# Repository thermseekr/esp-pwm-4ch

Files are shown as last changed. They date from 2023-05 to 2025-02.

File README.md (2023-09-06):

# ESP-PWM-4CH

ESP8266/ESP32 based board with 4x PWM output channels.

This board is designed to be driven by an Olimex ESP32-POE, ESP32-POE-ISO or Wemos D1 Mini modules.

The design considers that the board will be mounted on a PCB DIN rail holder offered by the Brazilian manufacturer Metaltex. Check [here](https://www.metaltex.com.br/produtos/componentes/suportes/sp7-suporte-para-montagem-de-placa-de-circuito-impresso-em-trilho-din) for details.

Heatsinks are included in the design as I wasn't sure about how much power the MOSFETs would dissipate. The first tests were performed using zero ohm resistors between the drivers and the transistors. A 5A load was applied and the transistor showed no noticeable temperature elevation. In version 2 I replaced the zero ohm resistors for 22 ohm to protect the drivers. Given the very low switching frequency and small loads I suppose the heatsinks are still not needed.

Expect some flicker when driving LEDs with the ESP8266. It gets much more stable when using the hardware PWMs of the ESP32.

There is a preferred version of this board with 8x PWM channels and individual pins for powering groups of two outputs, what enables driving the full 5A per channel. Click [here](https://github.com/thermseekr/esp-pwm-8ch) to check it.

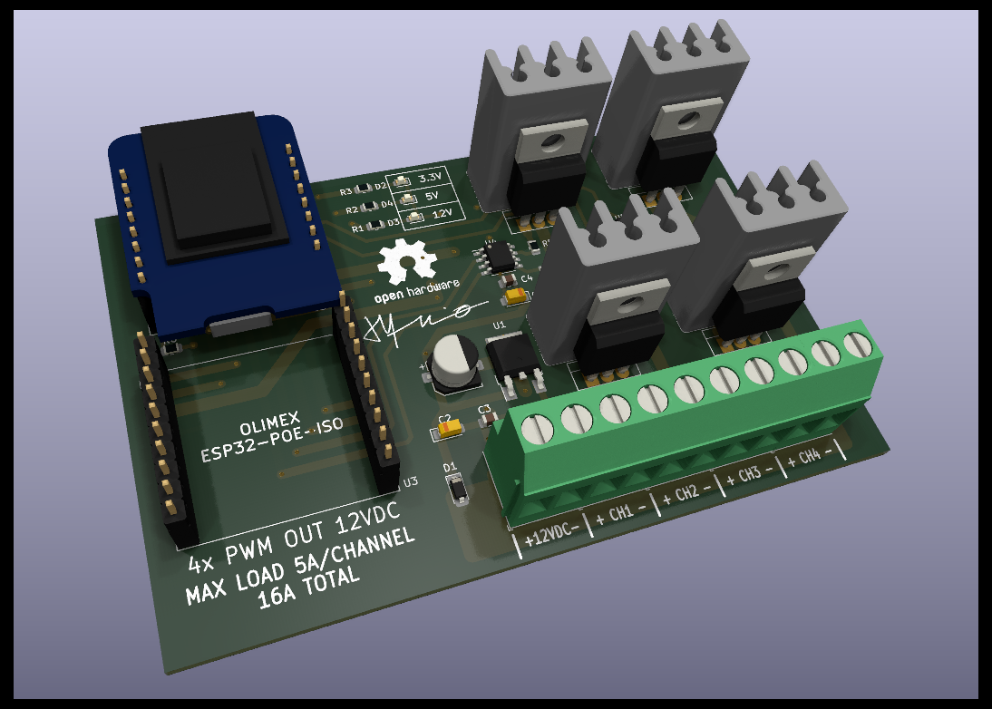
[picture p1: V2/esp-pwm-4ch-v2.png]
ESP-PWM-4CH


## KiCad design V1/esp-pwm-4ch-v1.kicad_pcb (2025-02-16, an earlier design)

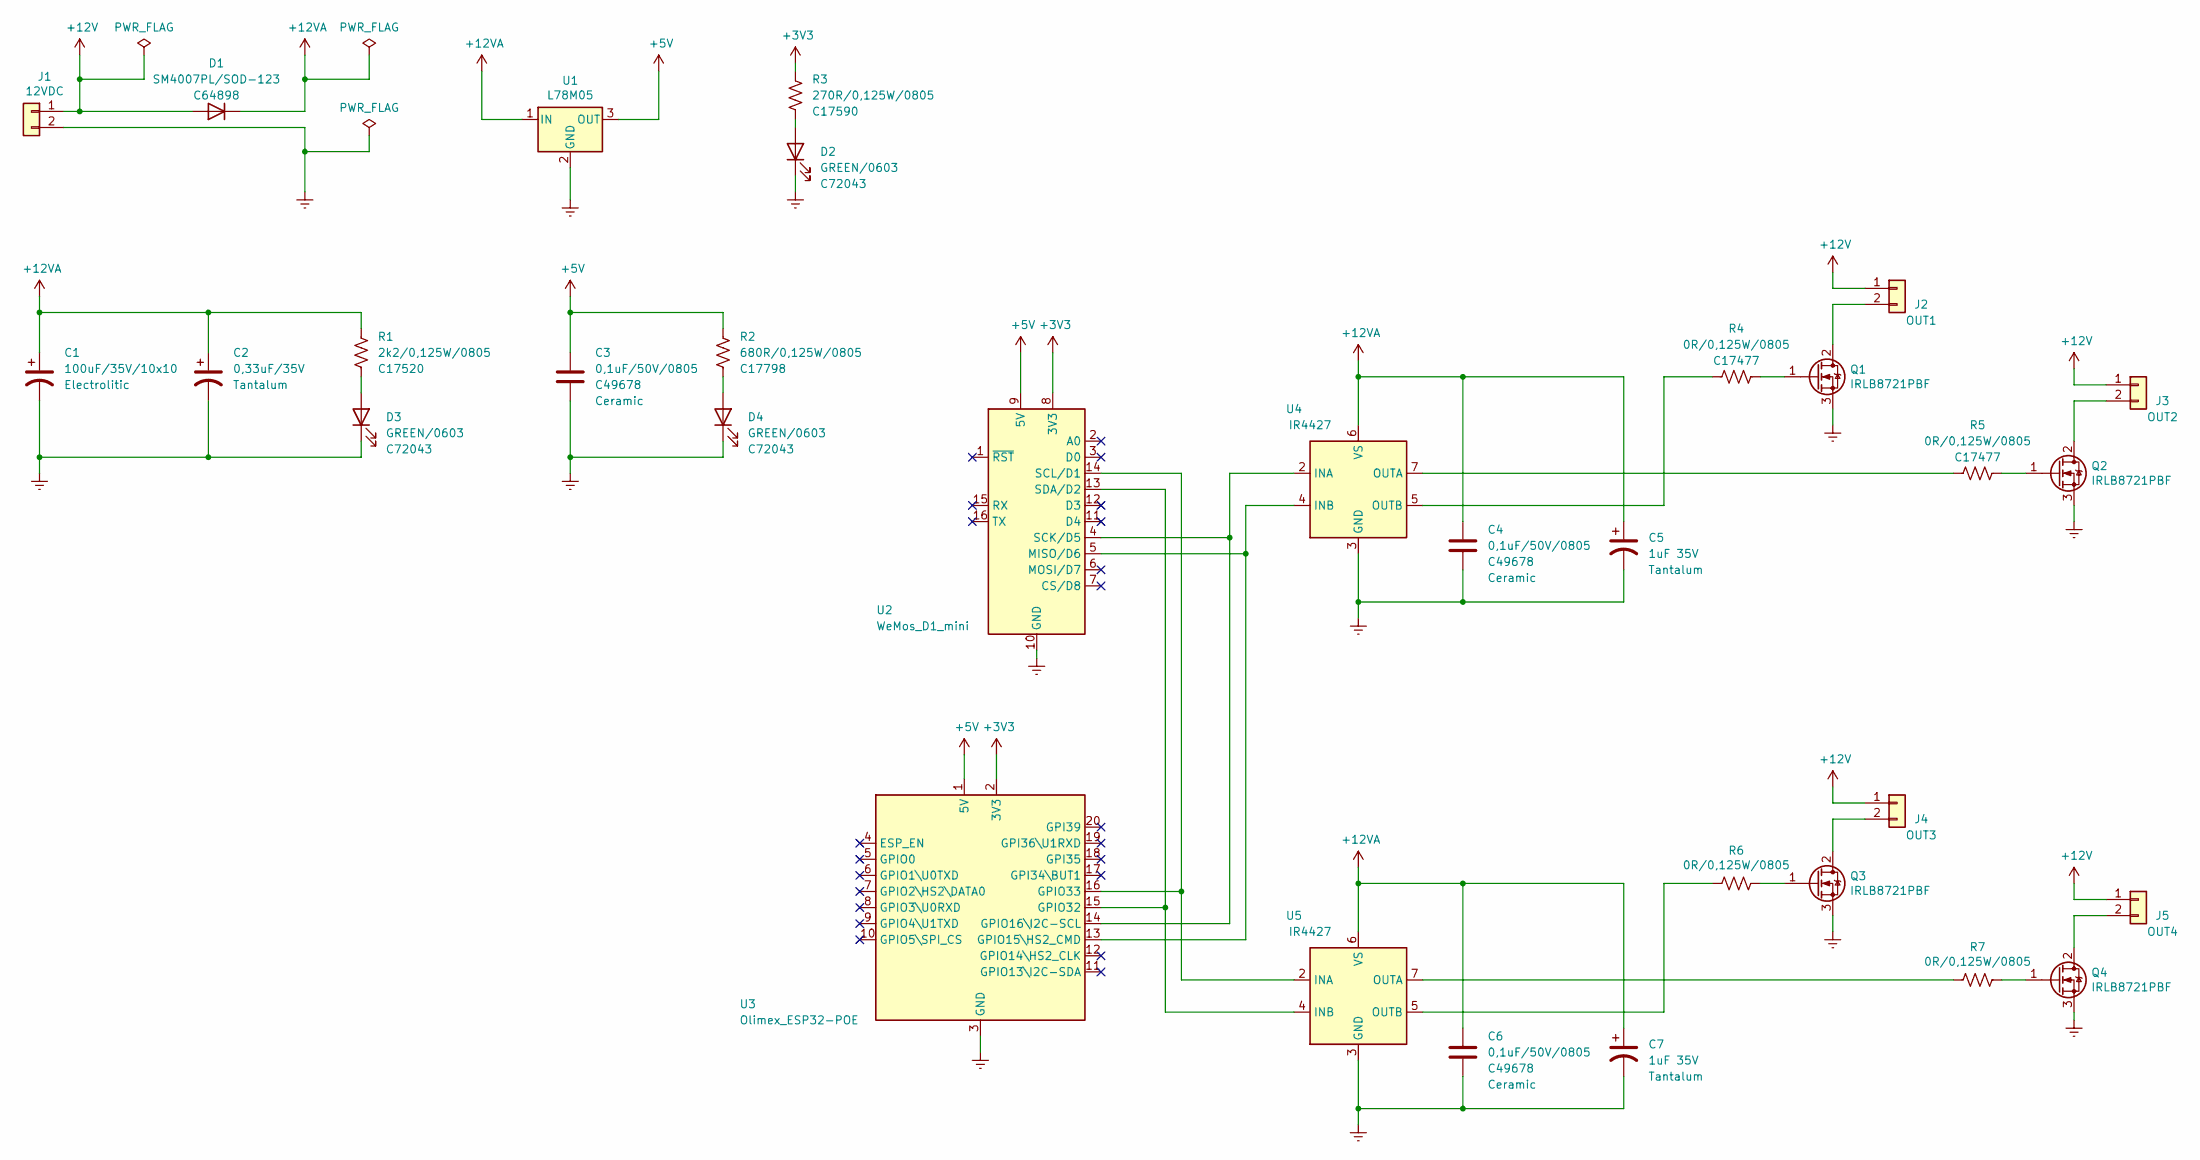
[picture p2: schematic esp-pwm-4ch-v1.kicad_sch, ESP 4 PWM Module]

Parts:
C1: 100uF/35V/10x10; CP_Elec_10x10; Mfr PN MAL214097001E3; JLCPCB BOM 0
C2: 0,33uF/35V; CP_EIA-3216-18_Kemet-A_Pad1.58x1.35mm_HandSolder; Mfr PN TAJA334K035RNJ; JLCPCB BOM 0
C3, C4, C6: 0,1uF/50V/0805; C_0805_2012Metric; Mfr PN CC0805KRX7R9BB104; JLCPCB BOM 1
C5, C7: 1uF 35V; CP_EIA-3216-18_Kemet-A_Pad1.58x1.35mm_HandSolder; Mfr PN TAJA105K035TNJ; JLCPCB BOM 0
D1: SM4007PL/SOD-123; D_SOD-123; Mfr PN SM4007PL; JLCPCB BOM 1
D2, D3, D4: GREEN/0603; LED_0603_1608Metric; Mfr PN 19-217/GHC-YR1S2/3T; JLCPCB BOM 1
J1: 12VDC; TerminalBlock_Phoenix_MKDS-3-2-5.08_1x02_P5.08mm_Horizontal; Mfr PN BR902V; JLCPCB BOM 0
J2: OUT1; TerminalBlock_Phoenix_MKDS-3-2-5.08_1x02_P5.08mm_Horizontal; Mfr PN BR902V; JLCPCB BOM 0
J3: OUT2; TerminalBlock_Phoenix_MKDS-3-2-5.08_1x02_P5.08mm_Horizontal; Mfr PN BR902V; JLCPCB BOM 0
J4: OUT3; TerminalBlock_Phoenix_MKDS-3-2-5.08_1x02_P5.08mm_Horizontal; Mfr PN BR902V; JLCPCB BOM 0
J5: OUT4; TerminalBlock_Phoenix_MKDS-3-2-5.08_1x02_P5.08mm_Horizontal; Mfr PN BR902V; JLCPCB BOM 0
Q1, Q2, Q3, Q4: IRLB8721PBF; TO-220-3_Vertical; Mfr PN IRLB8721PBF; JLCPCB BOM 0
R1: 2k2/0,125W/0805; R_0805_2012Metric; Mfr PN 0805W8F2201T5E; JLCPCB BOM 1
R2: 680R/0,125W/0805; R_0805_2012Metric; Mfr PN 0805W8F6800T5E; JLCPCB BOM 1
R3: 270R/0,125W/0805; R_0805_2012Metric; Mfr PN 0805W8F2700T5E; JLCPCB BOM 1
R4, R5, R6, R7: 0R/0,125W/0805; R_0805_2012Metric; Mfr PN 0805W8F0000T5E; JLCPCB BOM 1
U1: L78M05; TO-252-2; Mfr PN L78M05ABDT-TR; JLCPCB BOM 1
U2: WeMos_D1_mini; WEMOS_D1_mini_light_pads; Mfr PN D1 Mini Node MCU; JLCPCB BOM 0
U3: Olimex_ESP32-POE; Olimex_ESP32-POE_Pads; Mfr PN ESP32-POE; JLCPCB BOM 0
U4, U5: IR4427; SOIC-8_3.9x4.9mm_P1.27mm; Mfr PN IR4427STRPBF; JLCPCB BOM 0

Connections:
+3V3: R3.1, U2.8 (3V3), U3.2 (3V3)
+5V: C3.1, R2.1, U1.3 (OUT), U2.9 (5V), U3.1 (5V)
+12V: D1.2 (A), J1.1, J2.1, J3.1, J4.1, J5.1
+12VA: C1.1, C2.1, C4.1, C5.1, C6.1, C7.1, D1.1 (K), R1.1, U1.1 (IN), U4.6 (VS), U5.6 (VS)
GNDREF: C1.2, C2.2, C3.2, C4.2, C5.2, C6.2, C7.2, D2.1 (K), D3.1 (K), D4.1 (K), J1.2, Q1.3 (S), Q2.3 (S), Q3.3 (S), Q4.3 (S), U1.2 (GND), U2.10 (GND), U3.3 (GND), U4.3 (GND), U5.3 (GND)
unnamed: D2.2 (A), R3.2
unnamed: D3.2 (A), R1.2
unnamed: D4.2 (A), R2.2
unnamed: J2.2, Q1.2 (D)
unnamed: J3.2, Q2.2 (D)
unnamed: J4.2, Q3.2 (D)
unnamed: J5.2, Q4.2 (D)
unnamed: Q1.1 (G), R4.1
unnamed: Q2.1 (G), R5.1
unnamed: Q3.1 (G), R6.1
unnamed: Q4.1 (G), R7.1
unnamed: R4.2, U4.5 (OUTB)
unnamed: R5.2, U4.7 (OUTA)
unnamed: R6.2, U5.5 (OUTB)
unnamed: R7.2, U5.7 (OUTA)
unnamed: U2.4 (SCK/D5), U3.14 (GPIO16\I2C-SCL), U4.2 (INA)
unnamed: U2.5 (MISO/D6), U3.13 (GPIO15\HS2_CMD), U4.4 (INB)
unnamed: U2.13 (SDA/D2), U3.15 (GPIO32), U5.4 (INB)
unnamed: U2.14 (SCL/D1), U3.16 (GPIO33), U5.2 (INA)

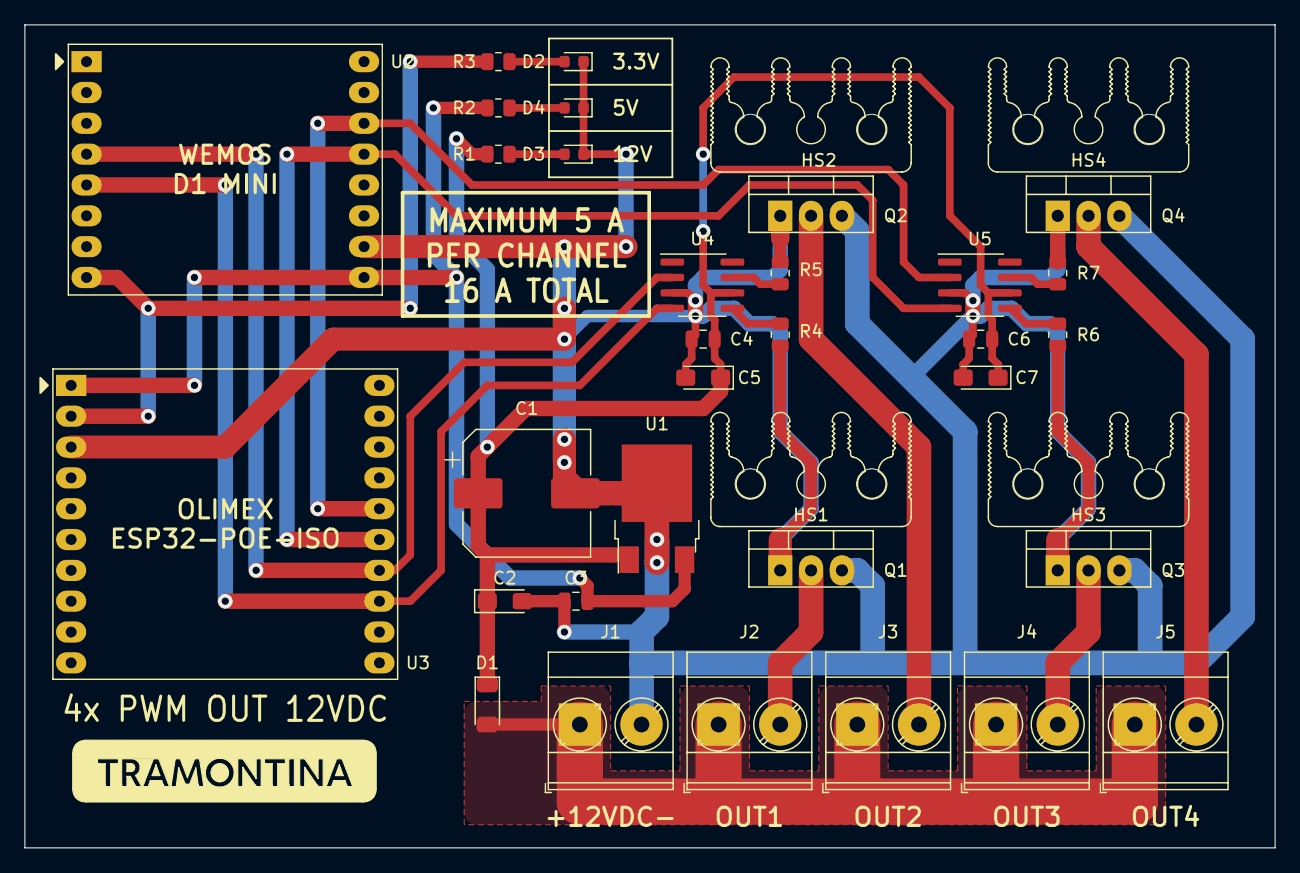
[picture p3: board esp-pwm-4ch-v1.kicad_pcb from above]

Board: 2 copper layers, 103.0 x 67.8 mm, 36 parts (0 on the bottom side), 24 nets.

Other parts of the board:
HS1, HS2, HS3, HS4: Heatsink_16x10x25mm_2xFixationM3

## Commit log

2023-05-20 Correct icloud errors
    [ESP-pwm-4ch-V1.kicad_pcb, ESP-pwm-4ch-V1.kicad_sch, ESP-pwm-4ch-V2.kicad_pcb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]
2023-05-20 Kicad version update
    [ESP-pwm-4ch-V2.kicad_pcb, ESP-pwm-4ch-V2.kicad_sch]
2023-08-20 Updated connectors
    [ESP-pwm-4ch-V2.kicad_pcb, ESP-pwm-4ch-V2.kicad_sch]
2023-09-06 Rename to lowercase
    [small-esp-pwm-4ch-v1.kicad_pcb, small-esp-pwm-4ch-v1.kicad_sch, small-esp-pwm-4ch-v2.kicad_pcb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]
2025-02-16 Saved in new Kicad version
    [esp-pwm-4ch-v1.kicad_pcb, esp-pwm-4ch-v1.kicad_sch]
